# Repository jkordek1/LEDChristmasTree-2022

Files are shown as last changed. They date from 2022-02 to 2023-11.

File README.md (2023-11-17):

# LEDChristmasTree-2022


[]()



## About
LED Christmas tree powered by 2xAAA batteries. It uses self-flashing LEDs (fast and slow). Device draws ~5 mA of current so the batteries should last through holidays!

There are a lot of LED christmas trees but this one is just a perfect size, uses small amount of power and it gives a really nice effect.

## GIFs and images


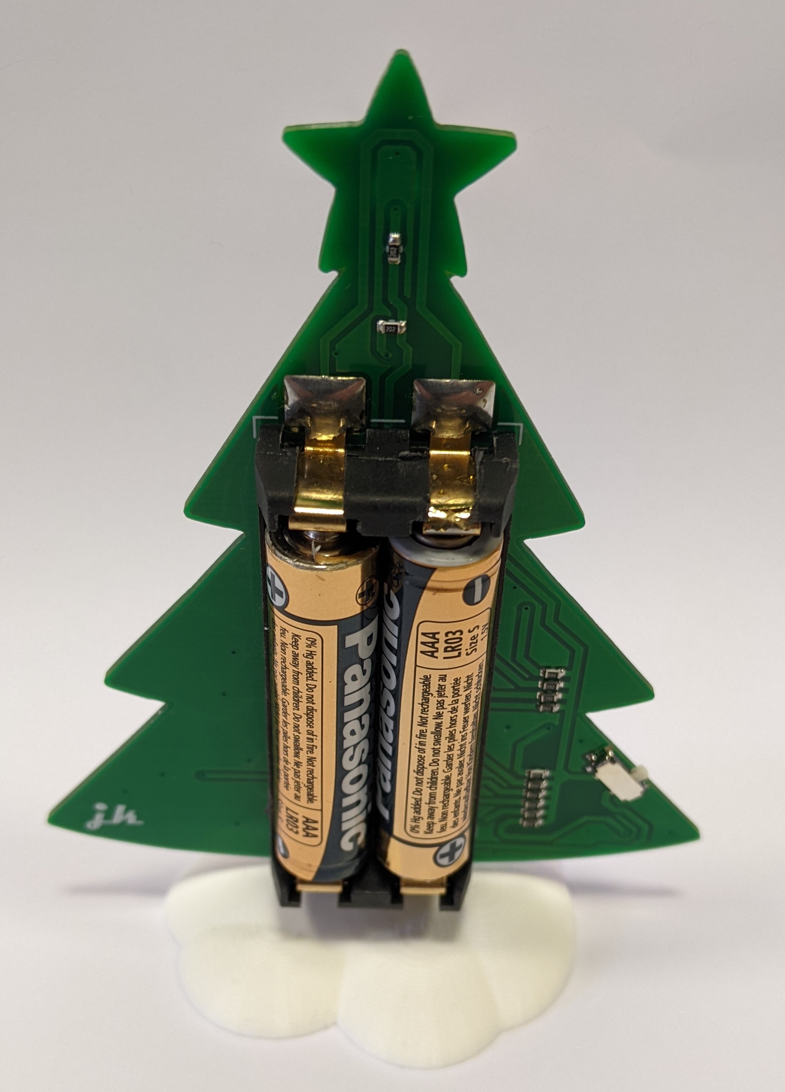
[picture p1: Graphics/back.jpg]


## YouTube
https://www.youtube.com/shorts/3aN1jUx8Kqs

## BOM
| #  | QTY | Component | Link
| --- | --- | --- | --- |
| 1  | 6 | 0807 RGB LED Fast  | [Aliexpress](https://www.aliexpress.com/item/32816748212.html?spm=a2g0o.order_detail.0.0.6c50f19cJa7Ddi) |
| 2  | 6 | 0807 RGB LED Slow  | [Aliexpress](https://www.aliexpress.com/item/32816748212.html?spm=a2g0o.order_detail.0.0.6c50f19cJa7Ddi) |
| 3  | 1 | 2xAAA Battery holder  | [Aliexpress](https://www.aliexpress.com/item/4001139676299.html?spm=a2g0o.order_list.0.0.21ef18022NrTgV) |
| 4  | 1 |  Slide switch  | [LCSC](https://lcsc.com/product-detail/Slide-Switches_Korean-Hroparts-Elec-K3-1296S-E2_C136659.html) |
| 5  | 12 | 2k 0603 resistor  | - |

## Project folder structure
    .
    ├── ...
    ├── Graphics                # Images and graphics
    ├── KiCadFiles              # Main KiCAD folder
    │   └── jlcpcb              # JLCPCB assembly and gerber folder
    ├── stand 3D model          # .stl file for stand
    └── ...

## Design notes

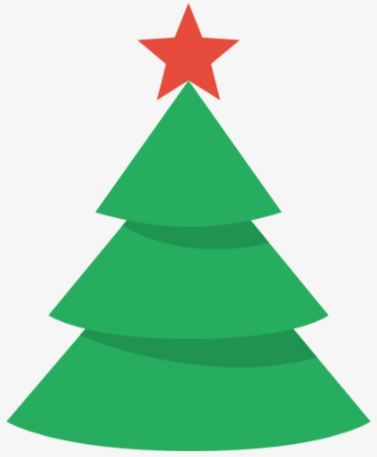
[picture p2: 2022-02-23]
Graphics/Christmas tree.PNG

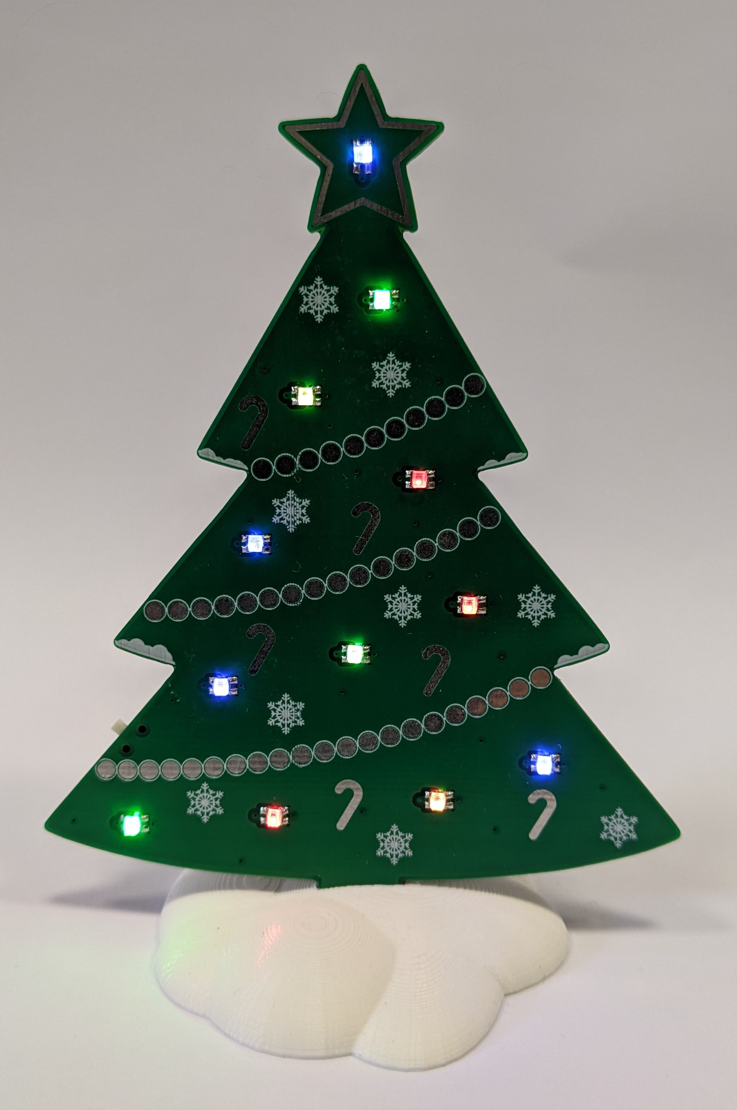
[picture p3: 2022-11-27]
Graphics/front.jpg

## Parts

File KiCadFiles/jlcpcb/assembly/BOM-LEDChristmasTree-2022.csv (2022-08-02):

Comment | Designator | Footprint | LCSC
2k | R1,R10,R11,R12,R2,R3,R4,R5,R6,R7,R8,R9 | R_0603_1608Metric | C22975

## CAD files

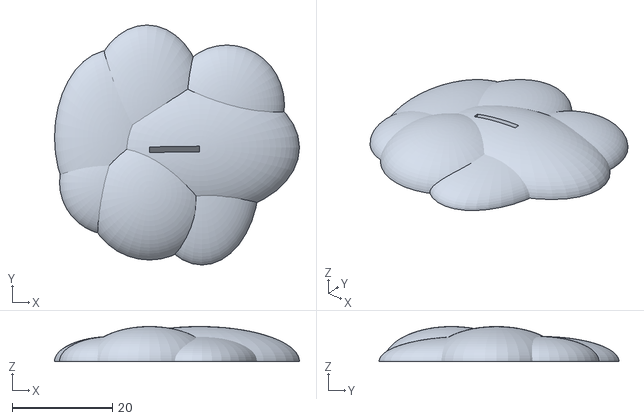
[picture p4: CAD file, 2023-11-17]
stand 3D model/stand.stl
49.0 x 48.0 x 7.00

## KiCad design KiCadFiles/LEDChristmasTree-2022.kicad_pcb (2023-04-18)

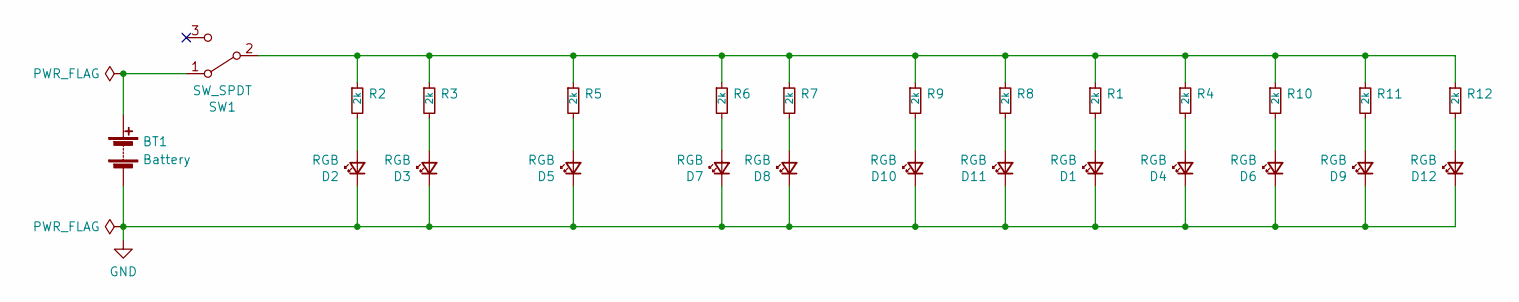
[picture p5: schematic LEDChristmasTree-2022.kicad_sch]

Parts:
BT1: Battery; 2xAAA-422-SMT
D1, D2, D3, D4, D5, D6, D7, D8, D9, D10, D11, D12: RGB; LED-0807
R1, R2, R3, R4, R5, R6, R7, R8, R9, R10, R11, R12: 2k; R_0603_1608Metric
SW1: SW_SPDT; SW_SPDT_PCM12

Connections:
GND: BT1.1 (-), D1.1 (K), D2.1 (K), D3.1 (K), D4.1 (K), D5.1 (K), D6.1 (K), D7.1 (K), D8.1 (K), D9.1 (K), D10.1 (K), D11.1 (K), D12.1 (K)
unnamed: BT1.3 (+), SW1.1 (A)
unnamed: D1.2 (A), R1.2
unnamed: D2.2 (A), R2.2
unnamed: D3.2 (A), R3.2
unnamed: D4.2 (A), R4.2
unnamed: D5.2 (A), R5.2
unnamed: D6.2 (A), R10.2
unnamed: D7.2 (A), R6.2
unnamed: D8.2 (A), R7.2
unnamed: D9.2 (A), R11.2
unnamed: D10.2 (A), R9.2
unnamed: D11.2 (A), R8.2
unnamed: D12.2 (A), R12.2
unnamed: R1.1, R2.1, R3.1, R4.1, R5.1, R6.1, R7.1, R8.1, R9.1, R10.1, R11.1, R12.1, SW1.2 (B)

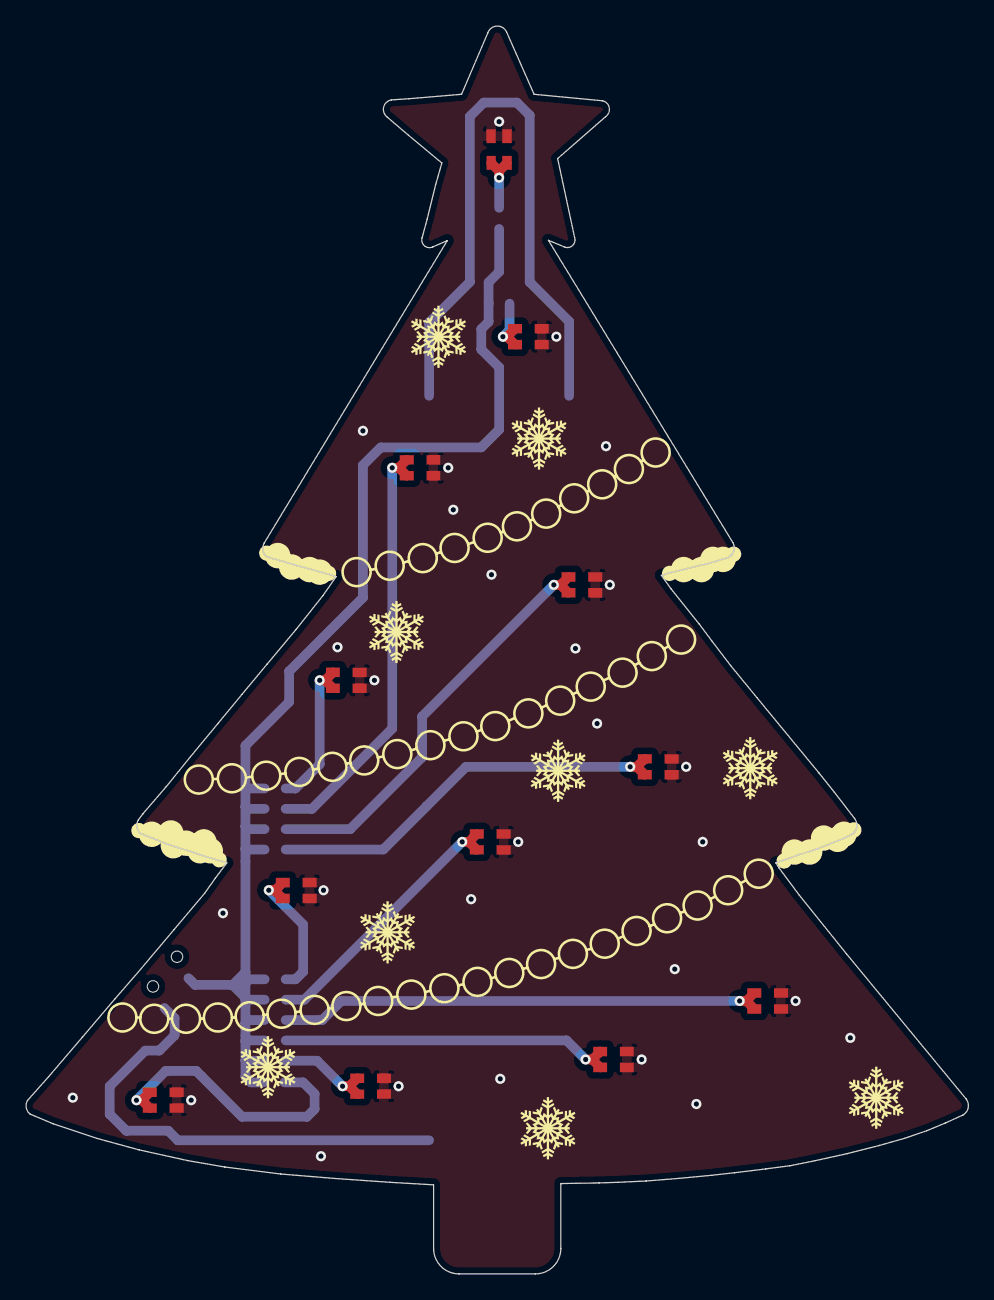
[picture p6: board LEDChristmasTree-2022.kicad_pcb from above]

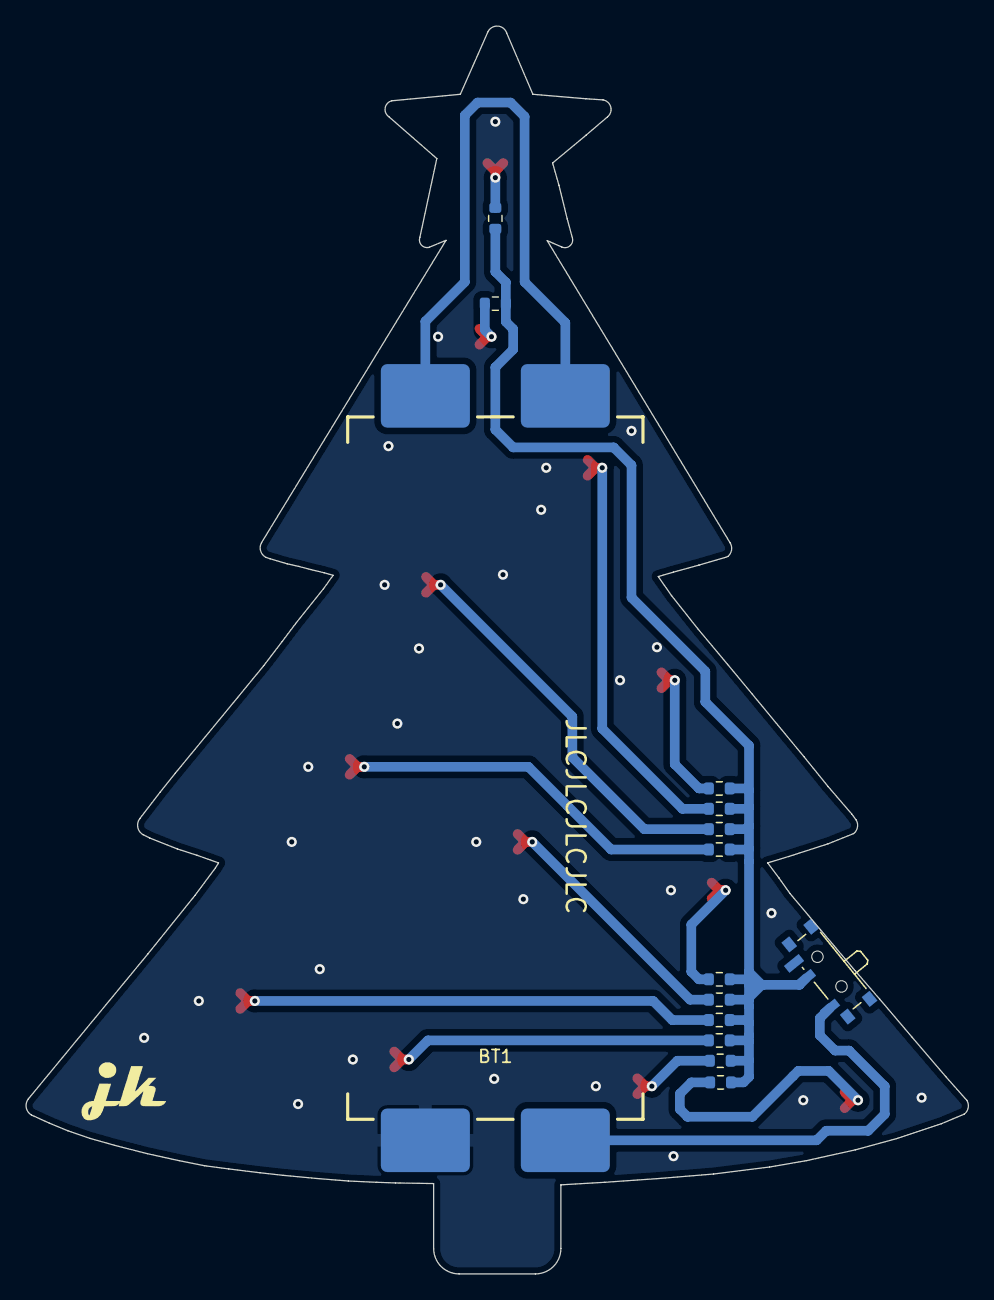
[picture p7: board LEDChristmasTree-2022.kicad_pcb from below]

Board: 2 copper layers, 74.0 x 98.1 mm, 26 parts (14 on the bottom side), 15 nets.

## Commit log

2022-02-23 edge cut
    [LEDChristmasTree-2022.kicad_pcb]
2022-03-22 fixed battery polarity
    [LEDChristmasTree-2022.kicad_pcb, LEDChristmasTree-2022.kicad_sch]
2023-04-18 folder structure
    [BOM-LEDChristmasTree-2022.csv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]
